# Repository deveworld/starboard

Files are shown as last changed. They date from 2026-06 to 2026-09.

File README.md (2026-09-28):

# Starboard

Starboard is a compact Hackpad macropad using only kit parts: six MX-style switches, one EC11 encoder, one 0.91 inch OLED, six SK6812 MINI-E LEDs, and a Seeed XIAO RP2040.

**Live demo → <https://deveworld.github.io/starboard/>** — interactive 3D viewer, specs, and downloads.

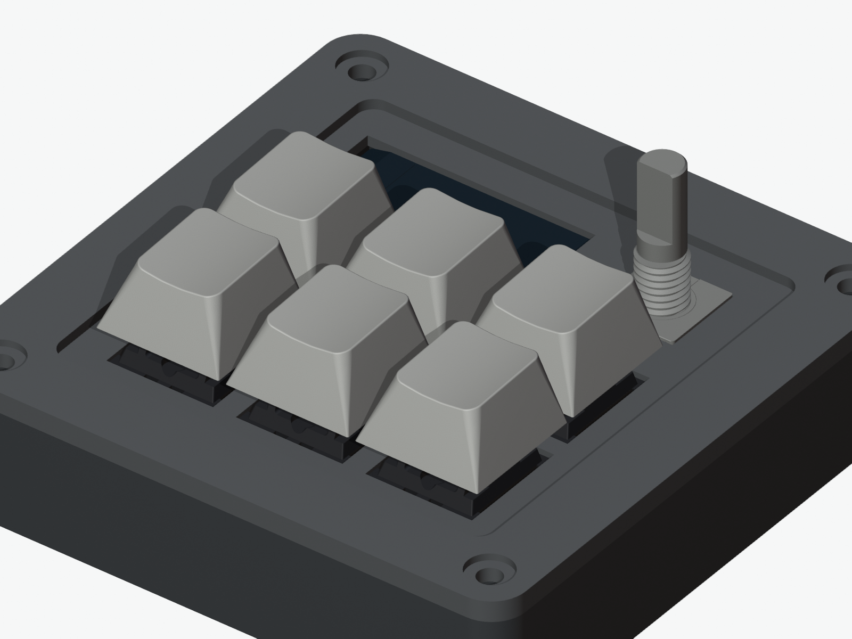
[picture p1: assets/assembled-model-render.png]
Starboard assembled render


The current case model is `CAD/assembled-model.STEP`, which includes the case and assembled components.

## Renders / Screenshots

| Schematic | PCB front | PCB back |
| :---: | :---: | :---: |
| Schematic | PCB front | PCB back |

## Bill of Materials

| Part | Qty |
| --- | ---: |
| Seeed XIAO RP2040 | 1 |
| MX-style mechanical switch | 6 |
| Blank DSA keycap | 6 |
| EC11 rotary encoder, 20mm D-shaft | 1 |
| 0.91 inch 128x32 OLED display | 1 |
| SK6812 MINI-E RGB LED | 6 |
| 1N4148 through-hole diode | 6 |
| M3x16mm screw | 4 |
| M3x5x4mm heatset insert | 4 |

## Design Summary

- PCB size: 63.0 x 63.0 mm, 2 layers
- Case size: 83.8 x 83.8 x 18.5 mm
- Inputs: 6 switches + 1 encoder
- MCU: Seeed XIAO RP2040
- Case: fully 3D printed sandwich case, top plate + bottom shell
- Switch plate: 1.5 mm thick, 14.2 x 14.2 mm MX cutouts
- Top shell: integrated 3.0 mm reinforced perimeter with screw head counterbores
- Fasteners: M3x16 screws into M3x5x4 heatset inserts

## Firmware

- QMK source: `Firmware/qmk/starboard/`
- Production archive: `production/firmware-qmk.zip`
- Prebuilt UF2: `production/firmware.uf2`
- Build command: `qmk compile -kb starboard -km default`
- Features: 6-key matrix, encoder rotation, encoder press, SSD1306 OLED, SK6812 RGB lighting
- Configurator: **<https://deveworld.github.io/starboard/configure/>** remaps keys and the encoder, sets lighting, writes custom OLED text and records macros over WebHID (Chrome/Edge). The firmware speaks the VIA protocol, with OLED settings on VIA's custom channel.
- Flashing an assembled board: hold FN (bottom-right key) and press the top-left key to enter the bootloader, then copy the UF2 onto the `RPI-RP2` drive.
- Wireless note: the current XIAO RP2040 hardware has no BLE radio; ZMK wireless should be reserved for a future BLE-controller revision.

## Submission Files

- `CAD/assembled-model.STEP`
- `Firmware/qmk/starboard/`
- `PCB/starboard.kicad_pro`
- `PCB/starboard.kicad_sch`
- `PCB/starboard.kicad_pcb`
- `production/firmware-qmk.zip`
- `production/gerbers.zip`
- `production/firmware.uf2`
- `production/Top.STEP`
- `production/Bottom.STEP`

## Verification

- ERC: 0 errors, 6 symbol-library mismatch warnings for SK6812 cache copies.
- DRC: 0 errors, 0 unconnected pads, 0 schematic parity issues; remaining warnings are silkscreen/cosmetic.
- Case V5 fit audit: all boolean clash and clearance checks pass.
- Firmware package: `keyboard.json` parses successfully, `production/firmware-qmk.zip` passes zip integrity check, and QMK compile succeeds for `starboard:default`.

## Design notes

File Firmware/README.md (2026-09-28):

# Starboard Firmware

This directory contains QMK firmware for Starboard.

Current target:

- MCU: Seeed XIAO RP2040
- Firmware: QMK
- Features: 6-key matrix, encoder rotation, encoder press, SSD1306 OLED, SK6812 RGB lighting
- Configuration: VIA protocol (4 dynamic layers, encoder map, 16 macros, RGB lighting), used by the web configurator at <https://deveworld.github.io/starboard/configure/>

The current PCB uses a XIAO RP2040, which has no BLE radio. ZMK is a good fit for a future wireless revision with a BLE-capable controller such as a XIAO nRF52840, but this hardware is better served by QMK.

The source archive for submission is `production/firmware-qmk.zip`. A compiled UF2 is available at `production/firmware.uf2`.

## Build

Copy `Firmware/qmk/starboard` into a QMK checkout under `keyboards/starboard`, then build:

```sh
qmk compile -kb starboard -km default
```

or:

```sh
make starboard:default
```

To flash, enter the bootloader and copy the generated `.uf2` file to the mounted `RPI-RP2` drive. On an assembled board, hold FN (bottom-right key) and press the top-left key (`QK_BOOT`), or hold the top-left key while plugging in USB (bootmagic). A bare XIAO can also use its BOOT button.

## Configurator protocol

Starboard answers standard VIA raw-HID commands (usage page `0xFF60`, usage `0x61`, 32-byte reports). OLED settings use VIA's custom channel `0`, handled in `keymaps/default/keymap.c` and stored in the EEPROM user datablock:

| Value id | Data | Meaning |
| ---: | --- | --- |
| `1` | 1 byte | Display mode: `0` status, `1` custom text, `2` off |
| `2`–`5` | 21 bytes | Custom text lines 1–4, printable ASCII |

`id_custom_set_value` applies a value immediately, `id_custom_save` persists all of them. The web app regenerates its keycode and RGB-mode tables from the QMK headers with `web/scripts/gen-qmk-data.py`, and `web/scripts/hw-test.mts` exercises the protocol against a connected board over Linux hidraw.

On Linux, give your user access to the raw HID interface once:

```sh
echo 'KERNEL=="hidraw*", ATTRS{idVendor}=="5354", ATTRS{idProduct}=="0001", TAG+="uaccess"' | sudo tee /etc/udev/rules.d/60-starboard.rules
sudo udevadm control --reload && sudo udevadm trigger
```

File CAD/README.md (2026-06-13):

# CAD Assets

- `assembled-model.STEP`: current Starboard case assembly for Fusion 360 screenshots/renders.

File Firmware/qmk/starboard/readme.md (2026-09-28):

# Starboard

QMK firmware for the Starboard macropad.

- Seeed XIAO RP2040
- 2x3 key matrix
- EC11 rotary encoder with push switch
- SSD1306 128x32 OLED over I2C
- 6 SK6812 MINI-E RGB LEDs

Build:

```sh
qmk compile -kb starboard -km default
```

Flash the generated UF2 by entering the bootloader (hold FN and press the top-left key, or hold the top-left key while plugging in USB), then copying the UF2 onto the `RPI-RP2` drive.

The default keymap enables VIA; configure it at <https://deveworld.github.io/starboard/configure/>.

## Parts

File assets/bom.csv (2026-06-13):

Refs | Value | Footprint | Qty | DNP
D1 | SK6812MINI-E | footprints:SK6812MINI-E_fixed | 1
D2 | SK6812MINI-E | footprints:SK6812MINI-E_fixed | 1
D3 | SK6812MINI-E | footprints:SK6812MINI-E_fixed | 1
D4 | SK6812MINI-E | footprints:SK6812MINI-E_fixed | 1
D5 | SK6812MINI-E | footprints:SK6812MINI-E_fixed | 1
D6 | SK6812MINI-E | footprints:SK6812MINI-E_fixed | 1
D7 | 1N4148 | Diode_THT:D_DO-35_SOD27_P7.62mm_Horizontal | 1
D8 | 1N4148 | Diode_THT:D_DO-35_SOD27_P7.62mm_Horizontal | 1
D9 | 1N4148 | Diode_THT:D_DO-35_SOD27_P7.62mm_Horizontal | 1
D10 | 1N4148 | Diode_THT:D_DO-35_SOD27_P7.62mm_Horizontal | 1
D11 | 1N4148 | Diode_THT:D_DO-35_SOD27_P7.62mm_Horizontal | 1
D12 | 1N4148 | Diode_THT:D_DO-35_SOD27_P7.62mm_Horizontal | 1
J1 | OLED_Display | footprints:SSD1306-0.91-OLED-4pin-128x32 | 1
SW1 | SW_Push | Button_Switch_Keyboard:SW_Cherry_MX_1.00u_PCB | 1
SW2 | SW_Push | Button_Switch_Keyboard:SW_Cherry_MX_1.00u_PCB | 1
SW3 | SW_Push | Button_Switch_Keyboard:SW_Cherry_MX_1.00u_PCB | 1
SW4 | SW_Push | Button_Switch_Keyboard:SW_Cherry_MX_1.00u_PCB | 1
SW5 | SW_Push | Button_Switch_Keyboard:SW_Cherry_MX_1.00u_PCB | 1
SW6 | SW_Push | Button_Switch_Keyboard:SW_Cherry_MX_1.00u_PCB | 1
SW7 | RotaryEncoder_Switch | footprints:RotaryEncoder_Alps_EC11E-Switch_Vertical_H20mm | 1
U1 | Seeed XIAO RP2040 | footprints:XIAO-Generic-Hybrid-14P-2.54-21X17.8MM | 1

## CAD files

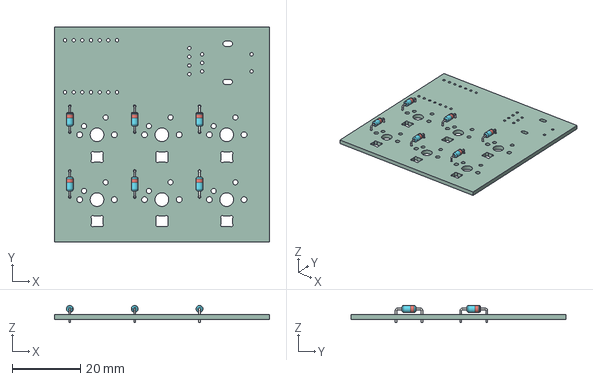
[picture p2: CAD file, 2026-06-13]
CAD/pcb.step
63.0 x 63.0 x 5.01 mm
D_DO-35_SOD27_P7.62mm_Horizontal x 6
starboard_PCB

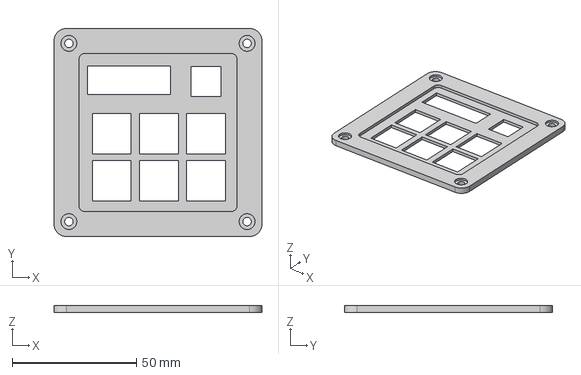
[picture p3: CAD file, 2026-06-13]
production/Top.STEP
83.8 x 83.8 x 3.00 mm

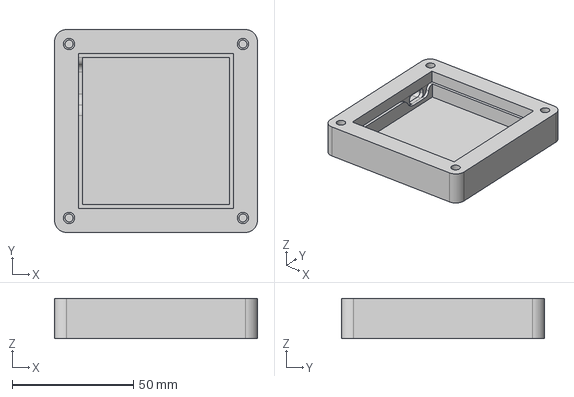
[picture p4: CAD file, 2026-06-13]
production/Bottom.STEP
83.8 x 83.8 x 16.6 mm

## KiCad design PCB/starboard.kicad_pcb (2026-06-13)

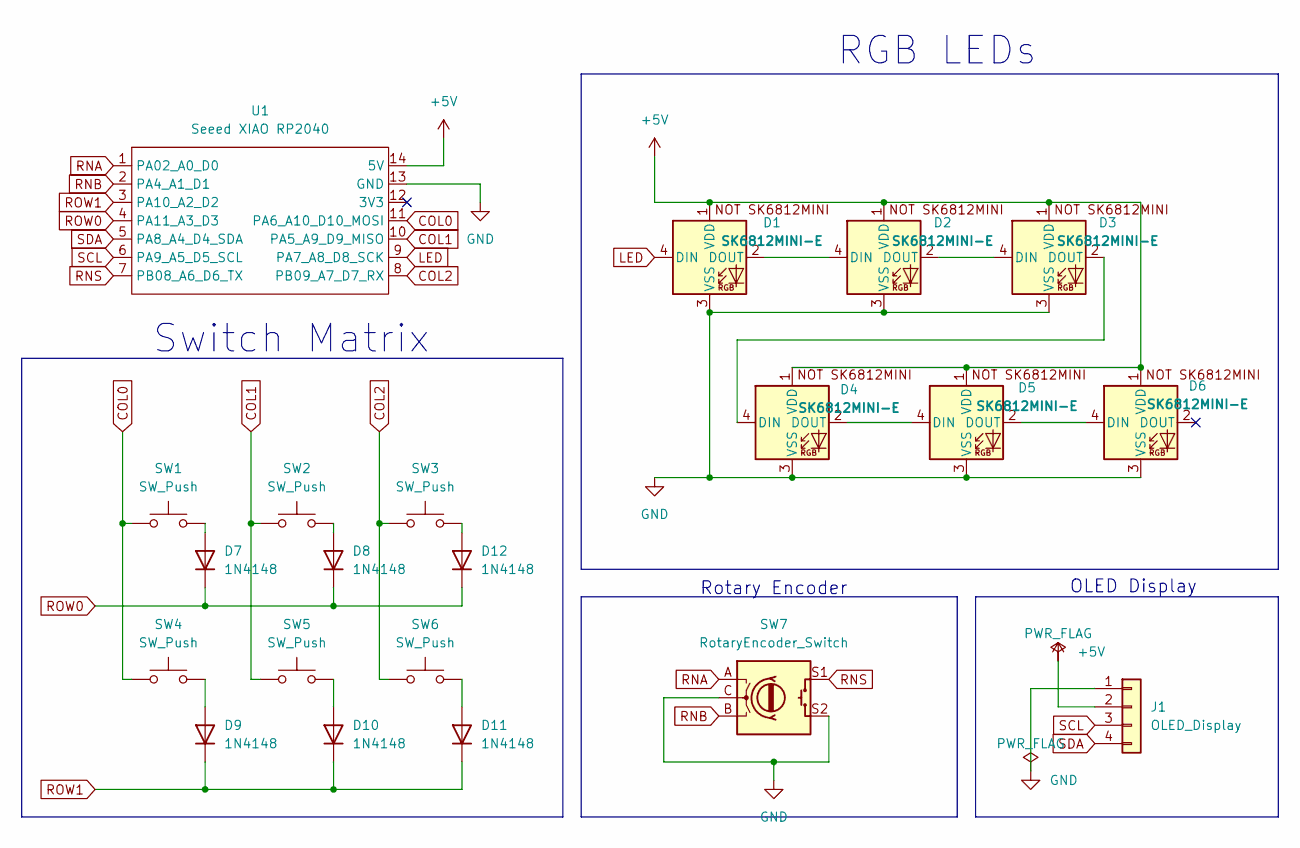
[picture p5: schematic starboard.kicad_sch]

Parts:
D1, D2, D3, D4, D5, D6: SK6812MINI-E; SK6812MINI-E_fixed
D7, D8, D9, D10, D11, D12: 1N4148; D_DO-35_SOD27_P7.62mm_Horizontal
J1: OLED_Display; SSD1306-0.91-OLED-4pin-128x32
SW1, SW2, SW3, SW4, SW5, SW6: SW_Push; SW_Cherry_MX_1.00u_PCB
SW7: RotaryEncoder_Switch; RotaryEncoder_Alps_EC11E-Switch_Vertical_H20mm
U1: Seeed XIAO RP2040; XIAO-Generic-Hybrid-14P-2.54-21X17.8MM

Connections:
+5V: D1.1 (VDD), D2.1 (VDD), D3.1 (VDD), D4.1 (VDD), D5.1 (VDD), D6.1 (VDD), J1.2, U1.14 (5V)
COL0: SW1.1, SW4.1, U1.11 (PA6_A10_D10_MOSI)
COL1: SW2.1, SW5.1, U1.10 (PA5_A9_D9_MISO)
COL2: SW3.1, SW6.1, U1.8 (PB09_A7_D7_RX)
GND: D1.3 (VSS), D2.3 (VSS), D3.3 (VSS), D4.3 (VSS), D5.3 (VSS), D6.3 (VSS), J1.1, SW7.C, SW7.S2, U1.13 (GND)
LED: D1.4 (DIN), U1.9 (PA7_A8_D8_SCK)
unnamed: D1.2 (DOUT), D2.4 (DIN)
unnamed: D2.2 (DOUT), D3.4 (DIN)
unnamed: D3.2 (DOUT), D4.4 (DIN)
unnamed: D4.2 (DOUT), D5.4 (DIN)
unnamed: D5.2 (DOUT), D6.4 (DIN)
unnamed: D7.2 (A), SW1.2
unnamed: D8.2 (A), SW2.2
unnamed: D9.2 (A), SW4.2
unnamed: D10.2 (A), SW5.2
unnamed: D11.2 (A), SW6.2
unnamed: D12.2 (A), SW3.2
RNA: SW7.A, U1.1 (PA02_A0_D0)
RNB: SW7.B, U1.2 (PA4_A1_D1)
RNS: SW7.S1, U1.7 (PB08_A6_D6_TX)
ROW0: D7.1 (K), D8.1 (K), D12.1 (K), U1.4 (PA11_A3_D3)
ROW1: D9.1 (K), D10.1 (K), D11.1 (K), U1.3 (PA10_A2_D2)
SCL: J1.3, U1.6 (PA9_A5_D5_SCL)
SDA: J1.4, U1.5 (PA8_A4_D4_SDA)

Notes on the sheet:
RGB LEDs
Rotary Encoder
OLED Display
Switch Matrix

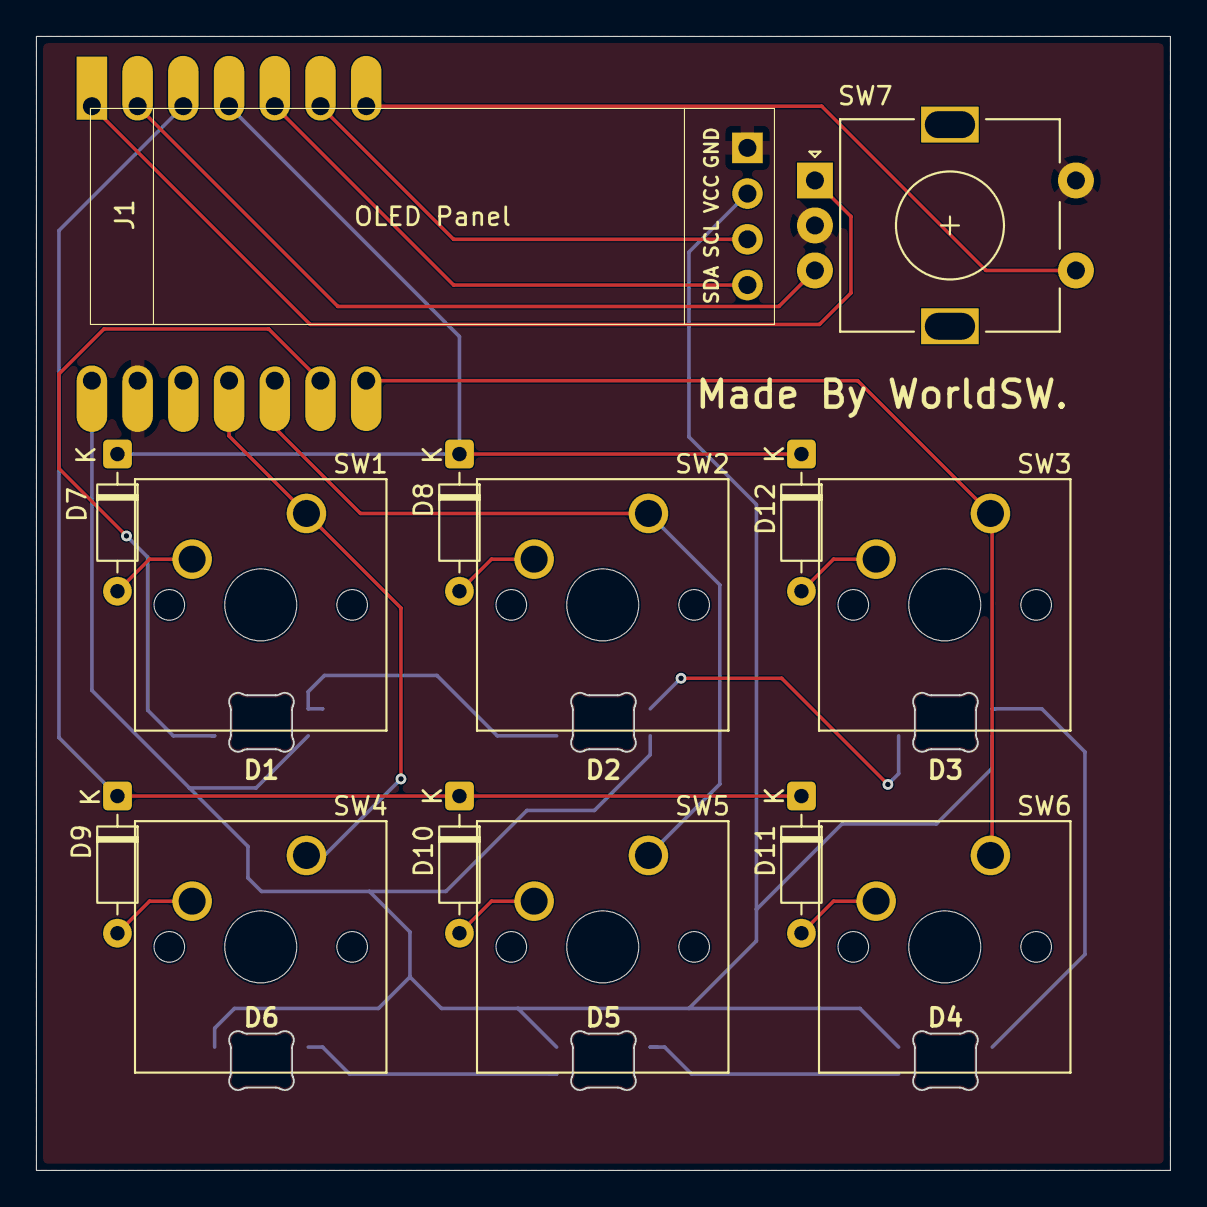
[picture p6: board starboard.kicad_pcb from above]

Board: 2 copper layers, 63.0 x 63.0 mm, 21 parts (1 on the bottom side), 24 nets.

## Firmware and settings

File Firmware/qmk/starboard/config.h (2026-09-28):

/* Copyright 2026 Starboard
 * SPDX-License-Identifier: GPL-2.0-or-later
 */

#pragma once

#define MATRIX_IO_DELAY 30

#define RP2040_BOOTLOADER_DOUBLE_TAP_RESET
#define RP2040_BOOTLOADER_DOUBLE_TAP_RESET_TIMEOUT 500U

#define I2C_DRIVER I2CD1
#define I2C1_SDA_PIN GP6
#define I2C1_SCL_PIN GP7

#define OLED_DISPLAY_ADDRESS 0x3C
#define OLED_DISPLAY_128X32
#define OLED_TIMEOUT 60000

#define WS2812_DI_PIN GP2
#define RGBLIGHT_LED_COUNT 6
#define RGBLIGHT_LIMIT_VAL 128
#define RGBLIGHT_DEFAULT_VAL 64
#define RGBLIGHT_DEFAULT_MODE RGBLIGHT_MODE_STATIC_LIGHT
#define RGBLIGHT_DEFAULT_HUE 170

#define RGBLIGHT_EFFECT_BREATHING
#define RGBLIGHT_EFFECT_RAINBOW_MOOD
#define RGBLIGHT_EFFECT_RAINBOW_SWIRL
#define RGBLIGHT_EFFECT_SNAKE
#define RGBLIGHT_EFFECT_KNIGHT
#define RGBLIGHT_EFFECT_TWINKLE

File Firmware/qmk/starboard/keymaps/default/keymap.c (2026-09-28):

/* Copyright 2026 Starboard
 * SPDX-License-Identifier: GPL-2.0-or-later
 */

#include QMK_KEYBOARD_H

enum layers {
    _BASE,
    _FN
};

const uint16_t PROGMEM keymaps[][MATRIX_ROWS][MATRIX_COLS] = {
    [_BASE] = LAYOUT(
        KC_ESC,  KC_UP,   KC_AUDIO_MUTE, KC_MEDIA_PLAY_PAUSE,
        KC_LEFT, KC_DOWN, LT(_FN, KC_RIGHT)
    ),
    [_FN] = LAYOUT(
        QK_BOOT, QK_UNDERGLOW_TOGGLE, QK_UNDERGLOW_MODE_NEXT, KC_MEDIA_STOP,
        QK_UNDERGLOW_HUE_UP, QK_UNDERGLOW_SATURATION_UP, QK_UNDERGLOW_VALUE_UP
    )
};

#ifdef ENCODER_MAP_ENABLE
const uint16_t PROGMEM encoder_map[][NUM_ENCODERS][NUM_DIRECTIONS] = {
    [_BASE] = {ENCODER_CCW_CW(KC_AUDIO_VOL_DOWN, KC_AUDIO_VOL_UP)},
    [_FN] = {ENCODER_CCW_CW(QK_UNDERGLOW_VALUE_DOWN, QK_UNDERGLOW_VALUE_UP)}
};
#endif

#ifdef OLED_ENABLE
#    define OLED_LINES 4
#    define OLED_LINE_CHARS 21

enum oled_mode {
    OLED_MODE_STATUS,
    OLED_MODE_TEXT,
    OLED_MODE_OFF,
    OLED_MODE_COUNT
};

// Persisted in the EEPROM user datablock; all zeroes (a fresh block) means status mode
typedef struct {
    uint8_t mode;
    char    lines[OLED_LINES][OLED_LINE_CHARS];
} oled_config_t;

_Static_assert(sizeof(oled_config_t) == EECONFIG_USER_DATA_SIZE, "EECONFIG_USER_DATA_SIZE must match oled_config_t");

static oled_config_t oled_config;

static const char *const layer_labels[] = {"Layer: BASE", "Layer: FN", "Layer: 2", "Layer: 3"};

void keyboard_post_init_user(void) {
    eeconfig_read_user_datablock(&oled_config, 0, sizeof(oled_config));
}

oled_rotation_t oled_init_user(oled_rotation_t rotation) {
    return OLED_ROTATION_180;
}

// Write a full-width line so stale characters are overwritten; unprintable bytes render as spaces
static void render_line(uint8_t line, const char *text) {
    char    buf[OLED_LINE_CHARS + 1];
    uint8_t i = 0;
    for (; i < OLED_LINE_CHARS && text[i]; i++) {
        buf[i] = (text[i] >= ' ' && text[i] <= '~') ? text[i] : ' ';
    }
    for (; i < OLED_LINE_CHARS; i++) {
        buf[i] = ' ';
    }
    buf[OLED_LINE_CHARS] = '\0';
    oled_set_cursor(0, line);
    oled_write(buf, false);
}

bool oled_task_user(void) {
    switch (oled_config.mode) {
        case OLED_MODE_OFF:
            oled_off();
            break;
        case OLED_MODE_TEXT:
            for (uint8_t i = 0; i < OLED_LINES; i++) {
                render_line(i, oled_config.lines[i]);
            }
            break;
        default: {
            uint8_t layer = get_highest_layer(layer_state);
            render_line(0, "Starboard");
            render_line(1, layer < ARRAY_SIZE(layer_labels) ? layer_labels[layer] : "Layer: ?");
            render_line(2, "XIAO RP2040");
            render_line(3, "");
            break;
        }
    }
    return false;
}

#    ifdef VIA_ENABLE
// VIA custom channel values, used by the web configurator
enum starboard_custom_value_id {
    id_oled_mode   = 1,
    id_oled_line_0 = 2, // lines 0-3 are ids 2-5; a line's 21 chars fit the 29 data bytes of a 32-byte packet
};

void via_custom_value_command_kb(uint8_t *data, uint8_t length) {
    // data = [ command_id, channel_id, value_id, value_data ]
    uint8_t *command_id = &(data[0]);
    uint8_t *channel_id = &(data[1]);
    uint8_t *value_id   = &(data[2]);
    uint8_t *value_data = &(data[3]);

    if (*channel_id == id_custom_channel) {
        bool is_line = *value_id >= id_oled_line_0 && *value_id < id_oled_line_0 + OLED_LINES;
        char *line   = is_line ? oled_config.lines[*value_id - id_oled_line_0] : NULL;

        switch (*command_id) {
            case id_custom_set_value:
                if (*value_id == id_oled_mode) {
                    oled_config.mode = value_data[0] < OLED_MODE_COUNT ? value_data[0] : OLED_MODE_STATUS;
                    return;
                }
                if (is_line) {
                    memcpy(line, value_data, OLED_LINE_CHARS);
                    return;
                }
                break;
            case id_custom_get_value:
                if (*value_id == id_oled_mode) {
                    value_data[0] = oled_config.mode;
                    return;
                }
                if (is_line) {
                    memcpy(value_data, line, OLED_LINE_CHARS);
                    return;
                }
                break;
            case id_custom_save:
                eeconfig_update_user_datablock(&oled_config, 0, sizeof(oled_config));
                return;
        }
    }

    *command_id = id_unhandled;
}
#    endif
#endif

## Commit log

2026-06-13 Starboard macropad submission
    XIAO RP2040 6-key + EC11 encoder macropad (Hackpad, kit parts).
    - PCB 63x63mm 2-layer (KiCad), gerbers + drill in production/
    - QMK firmware (Firmware/qmk/starboard) + compiled production/firmware.uf2
    - 3D-printed sandwich case (Top/Bottom STEP, assembled model)
    - BOM + schematic/PCB/case renders in README
    [Bottom.STEP, Top.STEP, bom.csv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]
2026-06-13 README: lead with assembled case render, move other images into a compact table
2026-06-13 Add static Next.js demo site (web/)
    Single-page showcase: hero render, features, specs, default keymap,
    KiCad design-file gallery, BOM, and download links. Next.js 15 App
    Router + Tailwind v4, static export to web/out/ (npm run build).
2026-06-13 Interactive 3D viewer + design-file lightbox
    - Replace the static hero render with a three.js GLTF viewer (orbit,
    zoom, auto-rotate); STEP converted to a 3 MB colored .glb. PNG stays
    as a poster/WebGL fallback.
    - Design-file figures open in a fullscreen lightbox on click (Esc or
    click to close).
2026-06-13 Fix blank 3D viewer: scale OrbitControls distance to model
    The GLB exports in metres (~0.084 max dim) but min/maxDistance were mm-scale
    (30/400), so OrbitControls clamped the camera ~30 m away and the model
    rendered as an invisible dot. Derive distance limits from the model size.
    Also set metadataBase and suppressHydrationWarning (browser extensions
    mutate <html> and trip React hydration).
2026-09-28 Firmware: rotate OLED 180° to match mounted orientation
    The OLED is mounted upside down relative to the firmware's default
    orientation, so the display read inverted on the assembled board.
    Return OLED_ROTATION_180 from oled_init_user and rebuild the shipped
    UF2 and source archive.
    Verified on hardware: text reads upright after flashing.
    Claude-Session: https://claude.ai/code/session_018coFuUbUnCNAf89oYNiHB5
    [keymap.c]
2026-09-28 Firmware: swap encoder pins so clockwise raises volume
    The encoder turned the wrong way on the assembled board (clockwise
    lowered volume). Swap pin_a/pin_b (GP27/GP26) in keyboard.json so the
    fix applies to every keymap, and rebuild the shipped UF2 and source
    archive.
    Verified on hardware: clockwise raises volume, OLED still upright.
    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
2026-09-28 Add a web configurator and VIA support to the firmware
    Firmware
    - Enable VIA: 4 dynamic layers, encoder map, 16 macros, RGB lighting
    - Add breathing, rainbow, swirl, snake, knight and twinkle effects
    - OLED on VIA custom channel 0: status / custom text / off mode and
    four 21-char lines, stored in the EEPROM user datablock
    Web (/configure)
    - WebHID client for the VIA protocol, plus a demo board that answers
    the same packets so the page works without hardware
    - Plan view drawn from PCB coordinates previews key labels, encoder
    bindings, underglow and the OLED (rendered with QMK's glcdfont)
    - Tabs for keys/encoder, lighting, display text and macros
    - Keycodes, RGB mode numbers and the fon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
    [config.h, keymap.c]
